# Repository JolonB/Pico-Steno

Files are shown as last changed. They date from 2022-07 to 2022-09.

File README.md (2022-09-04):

# Pico-Steno

An open-source Raspberry Pi Pico stenography keyboard.

I promise I'll write more here soon.

Gerber files can be found [here](hardware/gerber/).
I have not yet ordered a PCB with these gerber files, so they may have issues.

The bill of materials can be found [here](docs/bom/).

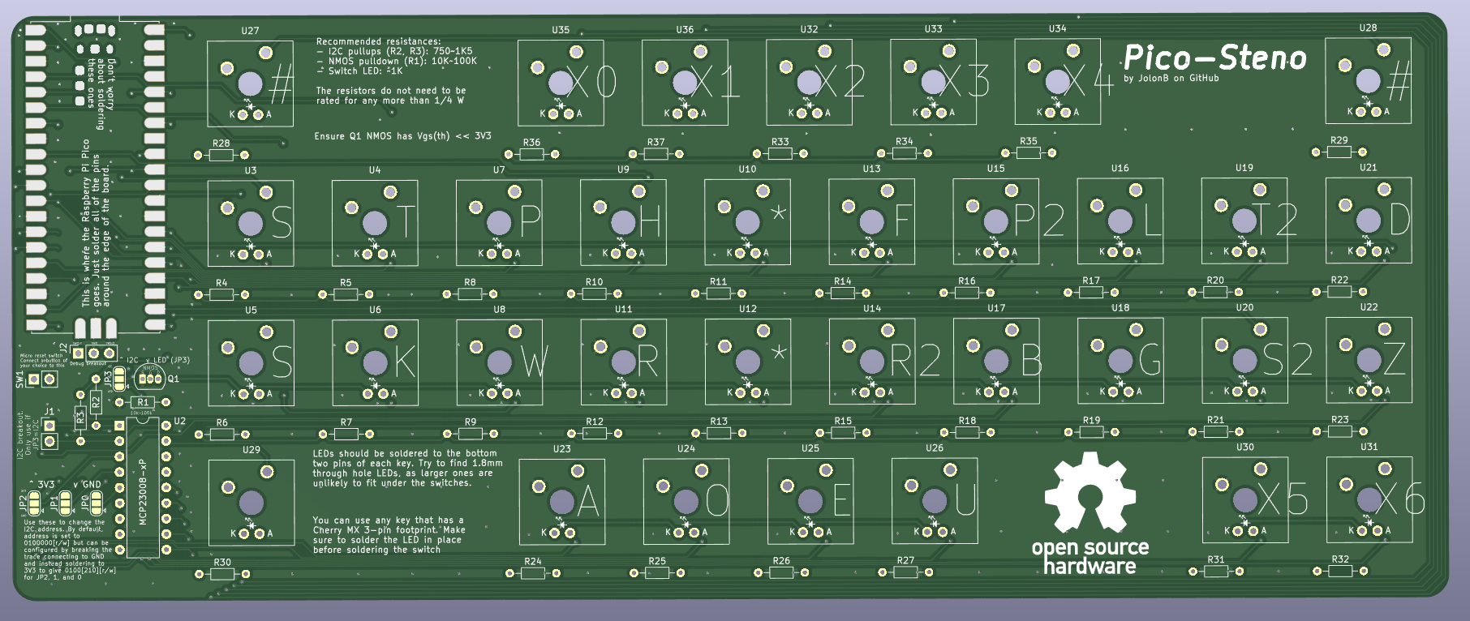
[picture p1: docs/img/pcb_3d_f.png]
pcb front


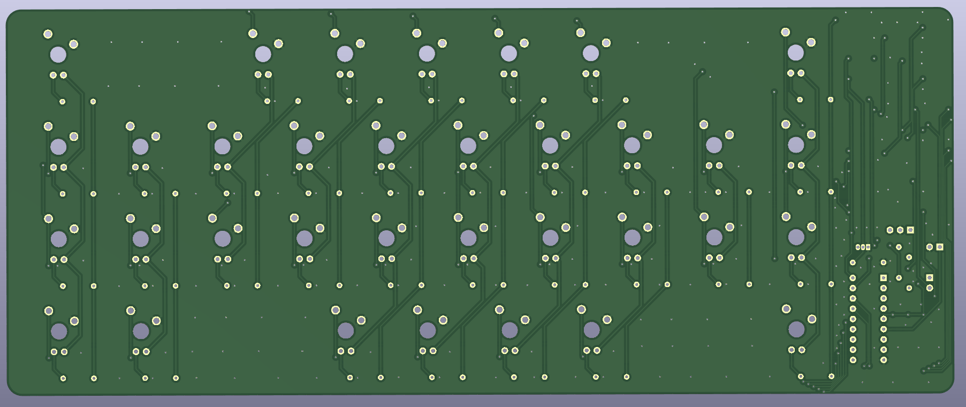
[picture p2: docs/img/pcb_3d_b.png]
pcb back


## Setup

### Flashing Pico

<!-- TODO add instructions for flashing the circuitpython firmware -->

To begin, you need to have `circup` installed so you can add libraries to your Pico.
Start by installing the dependencies:

```shell
sudo apt install -y git python3 python3-pip
```

And then install `circup`:

```shell
pip3 install --upgrade pip
pip3 install circup
```

You can update `circup` by running:

```shell
pip3 install --upgrade circup
```

Now, you can simply install the packages by plugging in your Pico which is running CircuitPython and running:

```shell
cd src/
circup install -r requirements.txt
```

### Compiling Code

To compile the code, you need `mpy-cross` installed on your PC.
You can download it from [here](https://adafruit-circuit-python.s3.amazonaws.com/index.html?prefix=bin/mpy-cross/) and download the latest version for your operating system (or look [here](https://learn.adafruit.com/welcome-to-circuitpython/frequently-asked-questions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) if the link is dead).

<!-- TODO add more notes here
Probably only need to compile the custom code, not the libraries. Might as well use circup (https://learn.adafruit.com/keep-your-circuitpython-libraries-on-devices-up-to-date-with-circup/prepare)
Later, could add an explanation for how to build a whole circuit python firmware with custom lib?? -->

### Loading .mpy files onto Pico

## Questions

### Why doesn't this use a keyboard matrix?

Good question.

1. The RPi Pico has enough GPIO pins to dedicate one to each key on a stenography keyboard.
Basically, I just though that was neat, so decided to do it that way.
I then decided I wanted optional extra keys, so added the IO extender.
1. This allows me to implement n-key rollover without needing any diodes; not that they are particularly expensive.

### Why is the circuit so messy?

That's what happens when each key is connected directly to the microcontroller without optimising the which switch connects to which pin.  
But hey, this is open source; if it bugs you, feel free to fork it!

## I can't detect my board

```shell
pip3 install adafruit-board-toolkit
python3 -c "import adafruit_board_toolkit.circuitpython_serial; print(adafruit_board_toolkit.circuitpython_serial.data_comports()[0].device)"
```

If you get `IndexError: tuple index out of range`, then no data port was detected.

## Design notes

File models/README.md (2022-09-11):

# Keycaps

The keycap has been generated by using the scripts made avilable by Robert Sheldon (rshelldiii on GitHub).
The keycap generator scripts for OpenSCAD can be found [here](https://github.com/rsheldiii/keyV2).

You can import `steno_key.stl` into the slicer of your choice.
I suggest reducing the top and bottom layer count to 3 and the wall line count to 2.
This is for two reasons: you don't need a super strong key and it allows more backlight through.
With just these changes, a full set of keys takes no more than 5 hours to print with a 0.16 mm layer height.

My `customizer.json` file used in the `customizer.scad` script is made available in this directory.
You should be able to import this and switch to the `flat` preset.
This may be useful if you want to make additional modifications to the keycap; adding labels, for example.

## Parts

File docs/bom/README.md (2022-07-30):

# Bill of Materials

The parts and prices shown in [`bom.csv`](bom.csv) are based on products available at DigiKey and, for most components, are only a suggestion.
The price isn't great, but you are able to purchase the same/similar components elsewhere for lower prices.
For example, AliExpress is a great place to look for the LEDs, MOSFETs, resistors, and even switches.  
As long as the component fits the footprint, there should be no issues.
Instead of buying proper Cherry MX switches, you could get pin-compatible switches from Kailh or Outemu for possibly half the price.  
If you want LED backlighting, make sure you choose an LED that fits in the switch.
The BOM uses a 1.8mm (green\*) LED which is the best type for Kailh switches.

\*Feel free to use any colour.

## Do I need to buy all of these?

No!

A "minimal" BOM is shown in [`bom_min.csv`](bom_min.csv).
This removes a few of the extra switches (marked by `Xn`) as well as the I2C expander than interfaces with them.

This *technically* isn't the true minimal BOM.
If you choose to, you can remove the LED backlighting by getting rid of:

- 1 switch (LED setting)
- 1 2N7000
- 27 LEDs
- 1 10k resistor
- 29 1k resistors

which will make the BOM consist of only the SC0915 (Raspberry Pi Pico) and the 26 remaining switches.
Buying the switches from AliExpress makes the true minimal *component* BOM no more than NZ$30 (excl. shipping).

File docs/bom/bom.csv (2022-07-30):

Index | Manufacturer Part Number | Manufacturer Name | Description | Requested Quantity 1 | Digi-Key Part Number 1 | Unit Price 1 | Extended Price 1 | Datasheet
1 | SC0915 | Raspberry Pi | RASPBERRY PI PICO RP2040 BOARD | 1 | 2648-SC0915CT-ND | 7.1 | 7.1 | https://datasheets.raspberrypi.com/pico/pico-datasheet.pdf
2 | MCP23008-E/P | Microchip Technology | IC I/O EXPANDER I2C 8B 18DIP | 1 | MCP23008-E/P-ND | 2.75 | 2.75 | https://ww1.microchip.com/downloads/en/DeviceDoc/MCP23008-MCP23S08-Data-Sheet-20001919F.pdf
3 | CF18JT10K0 | Stackpole Electronics Inc | RES 10K OHM 5% 1/8W AXIAL | 1 | CF18JT10K0CT-ND | 0.18 | 0.18 | https://www.seielect.com/catalog/sei-cf_cfm.pdf
4 | CF18JT1K00 | Stackpole Electronics Inc | RES 1K OHM 5% 1/8W AXIAL | 36 | CF18JT1K00CT-ND | 0.0584 | 2.1 | https://www.seielect.com/catalog/sei-cf_cfm.pdf
5 | 2N7000 | onsemi | MOSFET N-CH 60V 200MA TO92-3 | 1 | 2N7000FS-ND | 0.82 | 0.82 | https://rocelec.widen.net/view/pdf/orqxwkxkq1/ONSM-S-A0003544006-1.pdf?t.download=true&u=5oefqw
6 | MX1A-11NW | Cherry Americas LLC | SWITCH PUSH SPST-NO 0.01A 12V | 34 | CH160-ND | 1.4932 | 50.77 | https://media.digikey.com/pdf/Data%20Sheets/Cherry%20PDFs/MX%20Series.pdf
7 | WP4060GD | Kingbright | LED GREEN DIFFUSED T/H | 34 | 754-1373-ND | 0.496 | 16.86 | https://www.KingbrightUSA.com/images/catalog/SPEC/WP4060GD.pdf
 |  |  |  |  |  | Total | 80.58 | All prices in NZD

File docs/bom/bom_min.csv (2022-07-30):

Index | Manufacturer Part Number | Manufacturer Name | Description | Requested Quantity 1 | Digi-Key Part Number 1 | Unit Price 1 | Extended Price 1 | Datasheet
1 | SC0915 | Raspberry Pi | RASPBERRY PI PICO RP2040 BOARD | 1 | 2648-SC0915CT-ND | 7.1 | 7.1 | https://datasheets.raspberrypi.com/pico/pico-datasheet.pdf
2 | CF18JT10K0 | Stackpole Electronics Inc | RES 10K OHM 5% 1/8W AXIAL | 1 | CF18JT10K0CT-ND | 0.18 | 0.18 | https://www.seielect.com/catalog/sei-cf_cfm.pdf
3 | CF18JT1K00 | Stackpole Electronics Inc | RES 1K OHM 5% 1/8W AXIAL | 29 | CF18JT1K00CT-ND | 0.0584 | 1.69 | https://www.seielect.com/catalog/sei-cf_cfm.pdf
4 | 2N7000 | onsemi | MOSFET N-CH 60V 200MA TO92-3 | 1 | 2N7000FS-ND | 0.82 | 0.82 | https://rocelec.widen.net/view/pdf/orqxwkxkq1/ONSM-S-A0003544006-1.pdf?t.download=true&u=5oefqw
5 | MX1A-11NW | Cherry Americas LLC | SWITCH PUSH SPST-NO 0.01A 12V | 27 | CH160-ND | 1.4932 | 40.32 | https://media.digikey.com/pdf/Data%20Sheets/Cherry%20PDFs/MX%20Series.pdf
6 | WP4060GD | Kingbright | LED GREEN DIFFUSED T/H | 27 | 754-1373-ND | 0.496 | 13.39 | https://www.KingbrightUSA.com/images/catalog/SPEC/WP4060GD.pdf
 |  |  |  |  |  | Total | 63.5 | All prices in NZD

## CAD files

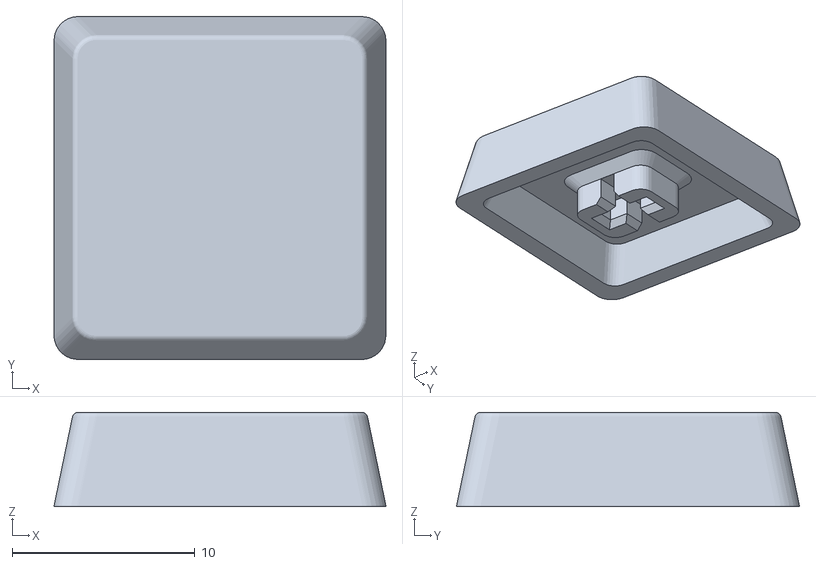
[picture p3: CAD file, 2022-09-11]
models/steno_key.stl
18.2 x 18.8 x 5.16

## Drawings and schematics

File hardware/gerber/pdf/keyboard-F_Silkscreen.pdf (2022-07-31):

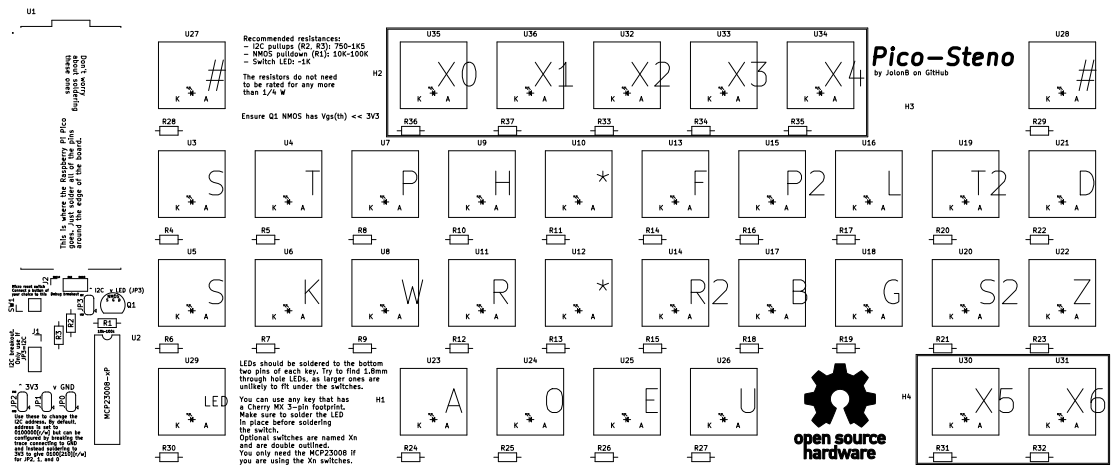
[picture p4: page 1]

The resistors do not need
to be rated for any more
than 1/4 W

by JolonB on GitHub

Debug breakout SWCLK This is where the Raspberry Pi Pico goes. Just solder all of the pins around the edge of the board.

GND Use these to change the
through hole LEDs, as larger ones are unlikely to fit under the switches. Micro reset switch Connect a button of your choice to this
U2 MCP23008-xP

and are double outlined. You only need the MCP23008 if you are using the Xn switches. D

two pins of each key. Try to find 1.8mm

a Cherry MX 3-pin footprint. Make sure to solder the LED

I2C address. By default, address is set to
0100000[r/w] but can be
configured by breaking the
trace connecting to GND
and instead soldering to
3V3 to give 0100[210][r/w]

in place before soldering
the switch. Optional switches are named Xn

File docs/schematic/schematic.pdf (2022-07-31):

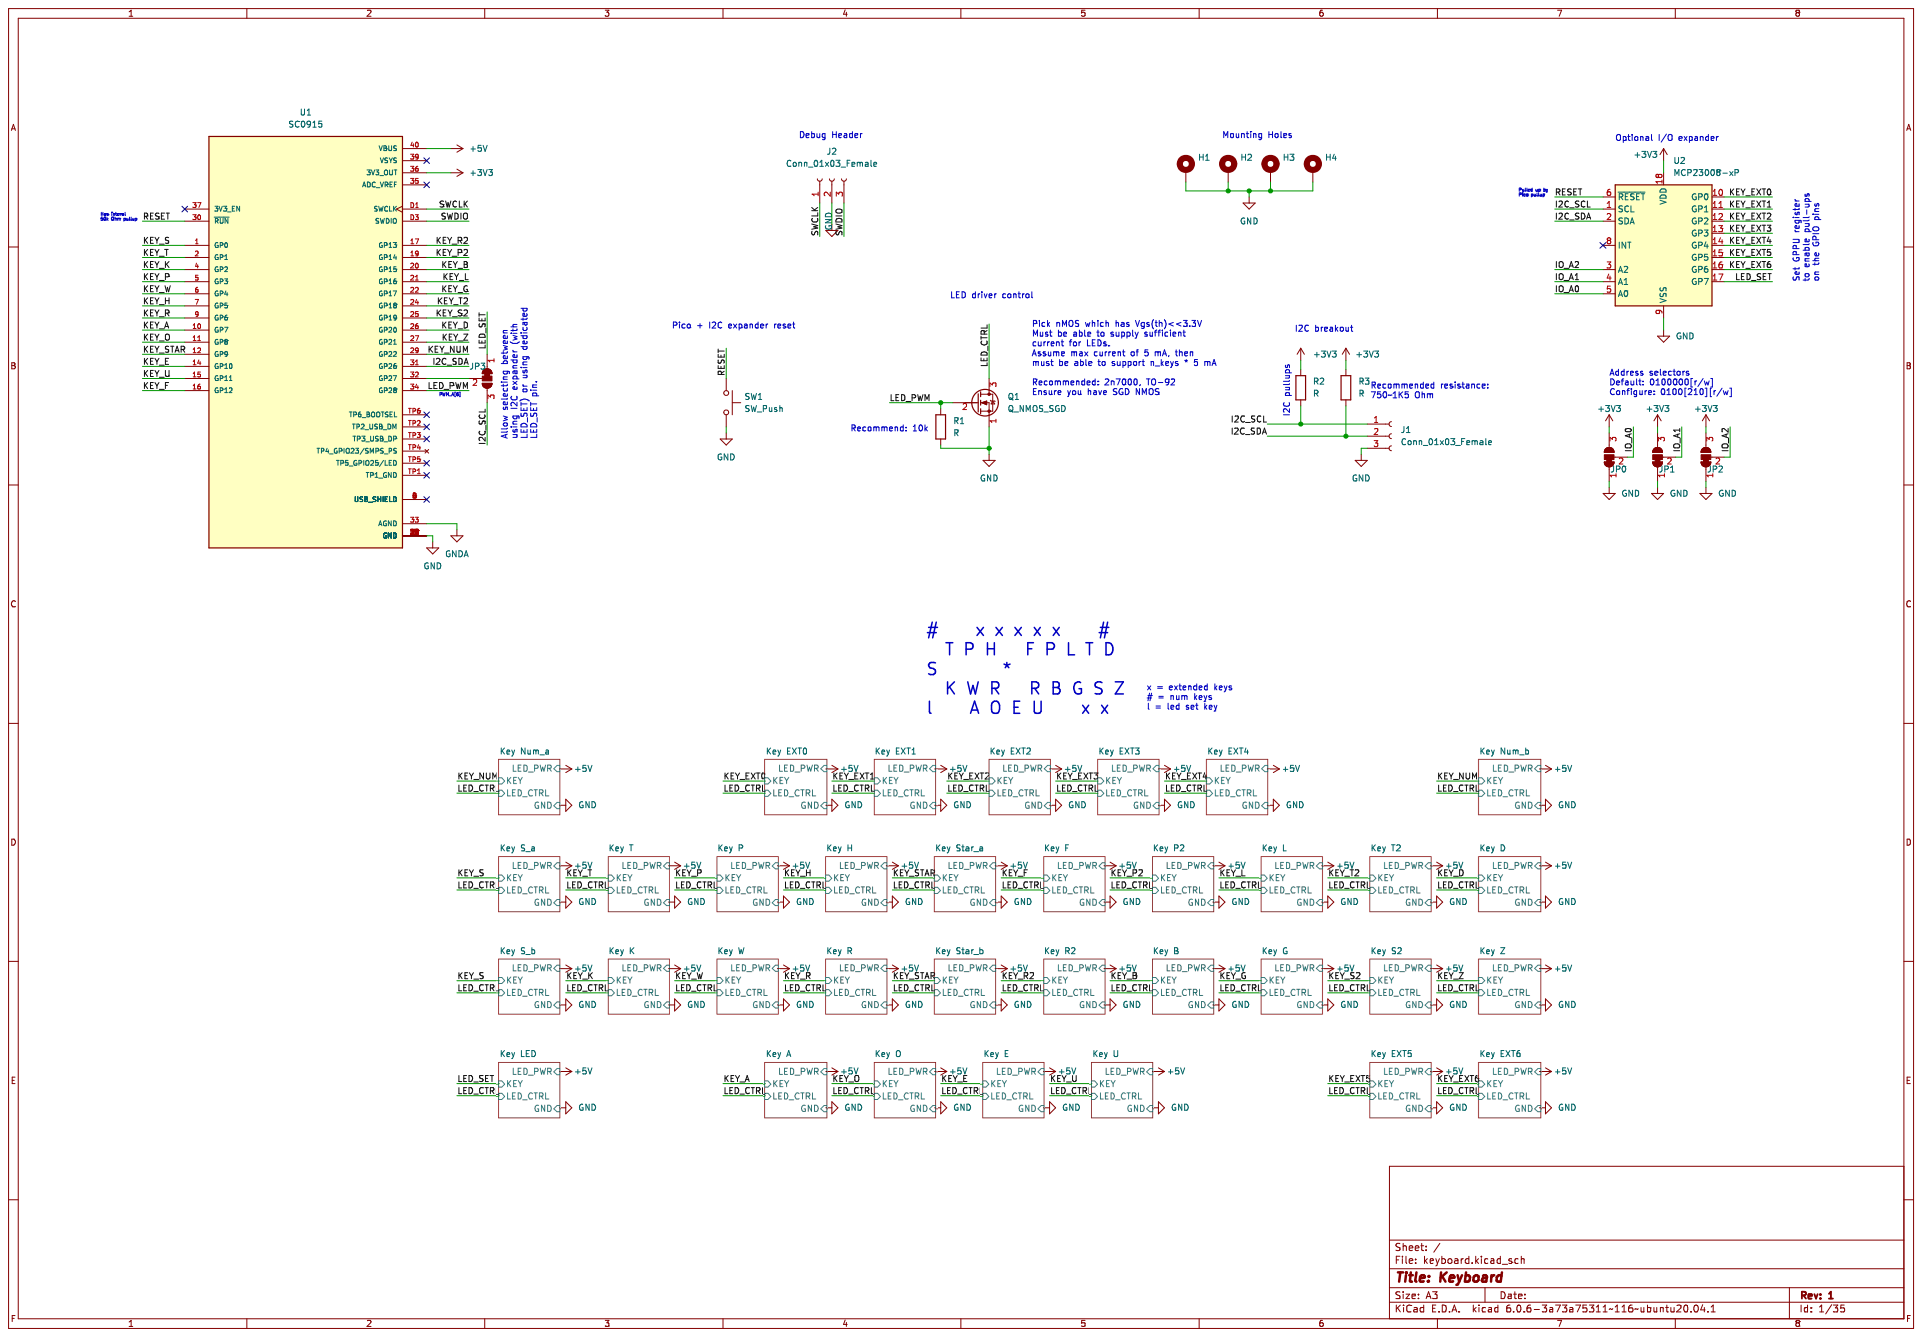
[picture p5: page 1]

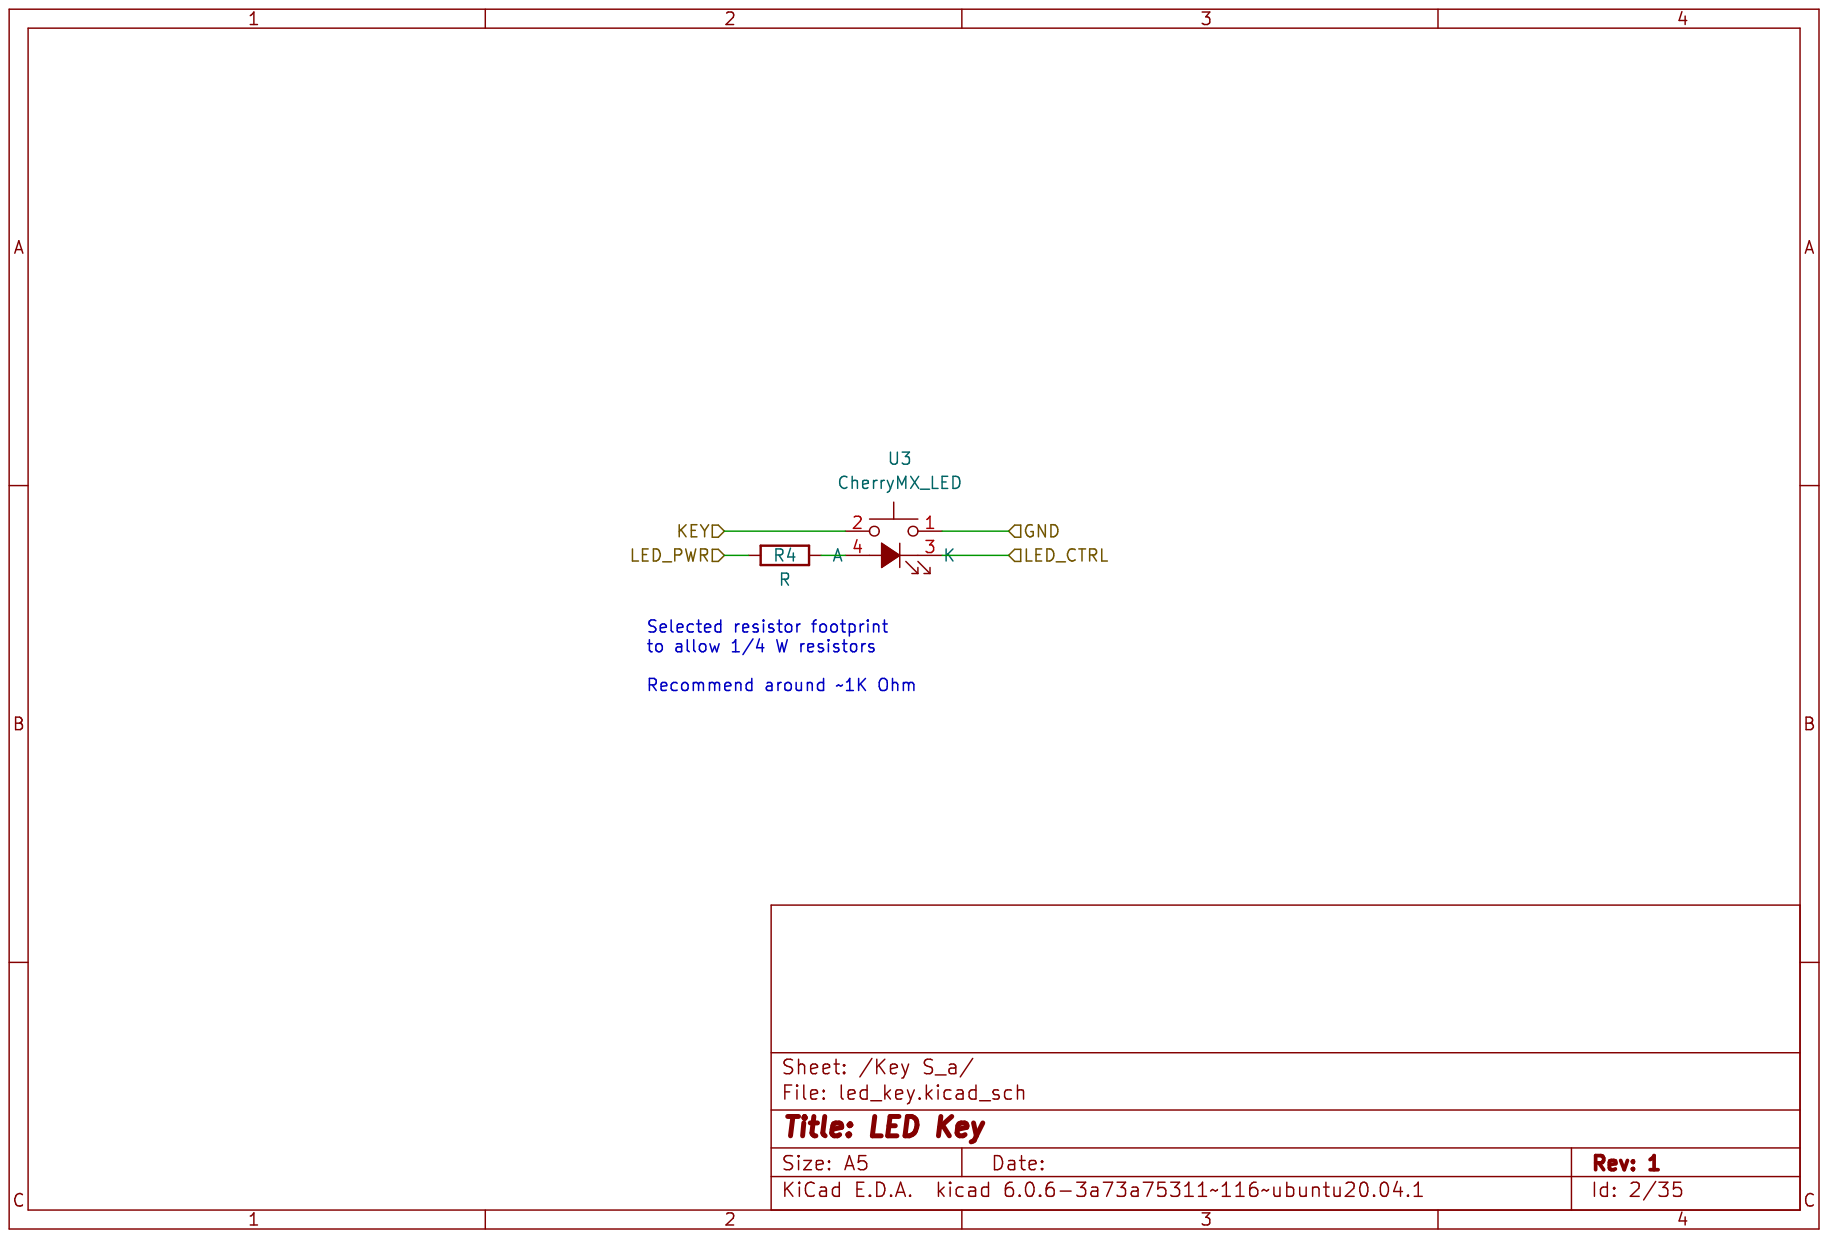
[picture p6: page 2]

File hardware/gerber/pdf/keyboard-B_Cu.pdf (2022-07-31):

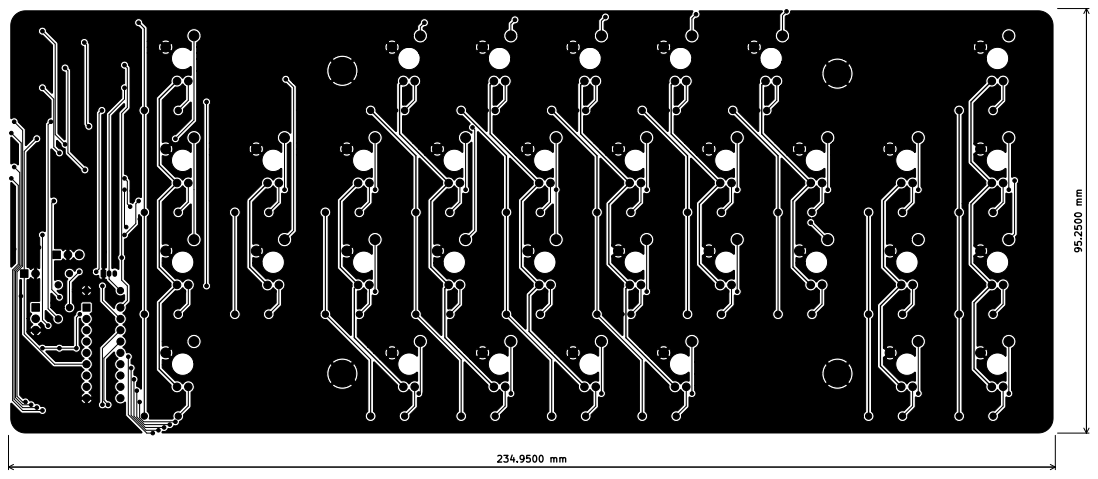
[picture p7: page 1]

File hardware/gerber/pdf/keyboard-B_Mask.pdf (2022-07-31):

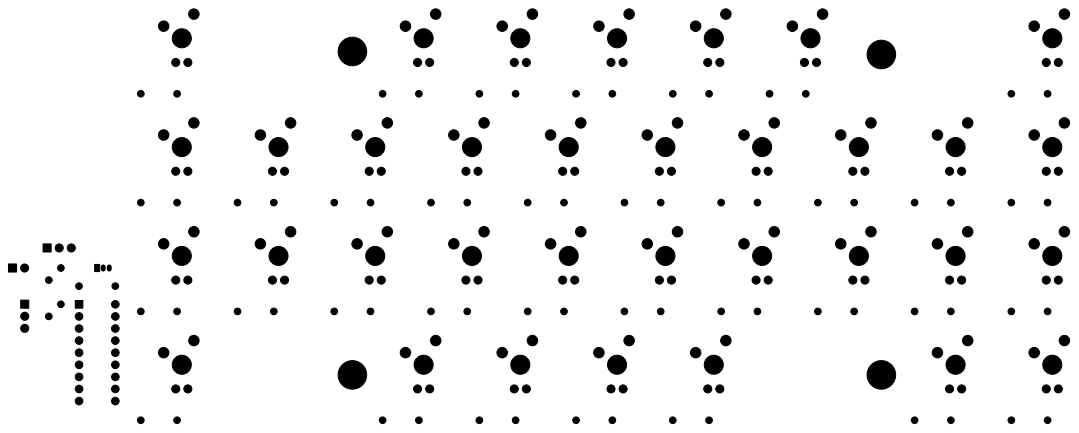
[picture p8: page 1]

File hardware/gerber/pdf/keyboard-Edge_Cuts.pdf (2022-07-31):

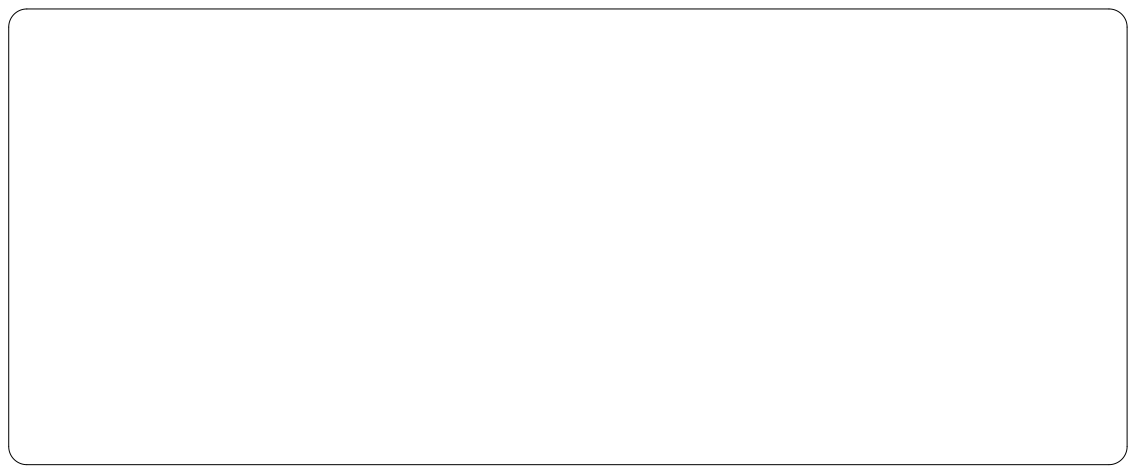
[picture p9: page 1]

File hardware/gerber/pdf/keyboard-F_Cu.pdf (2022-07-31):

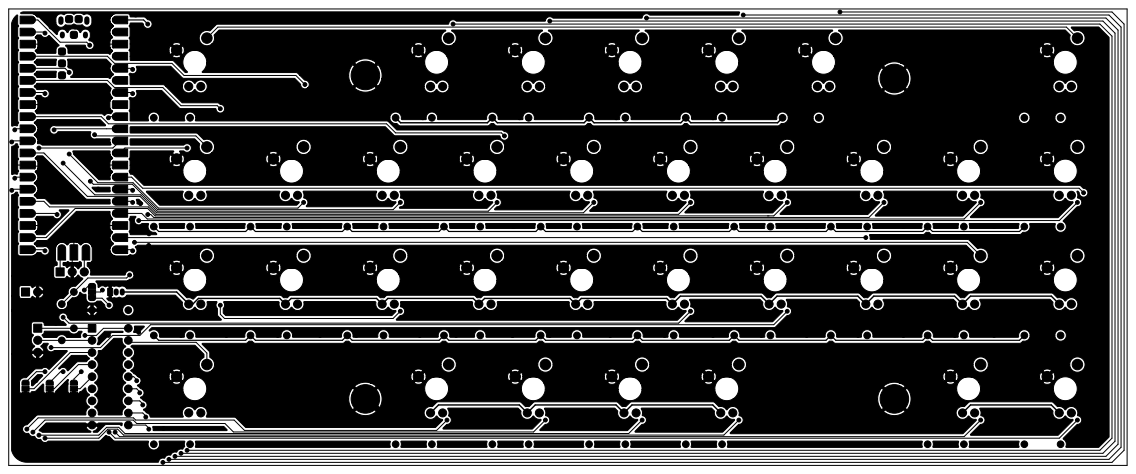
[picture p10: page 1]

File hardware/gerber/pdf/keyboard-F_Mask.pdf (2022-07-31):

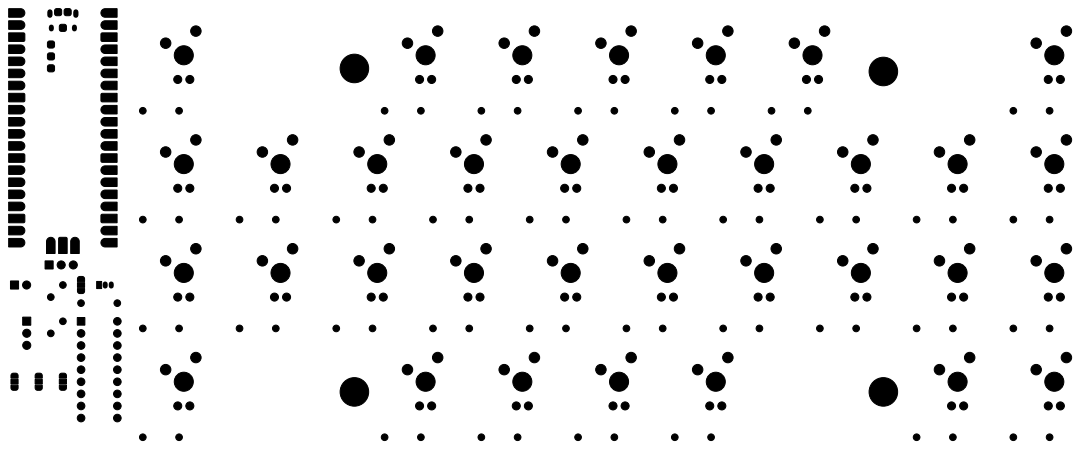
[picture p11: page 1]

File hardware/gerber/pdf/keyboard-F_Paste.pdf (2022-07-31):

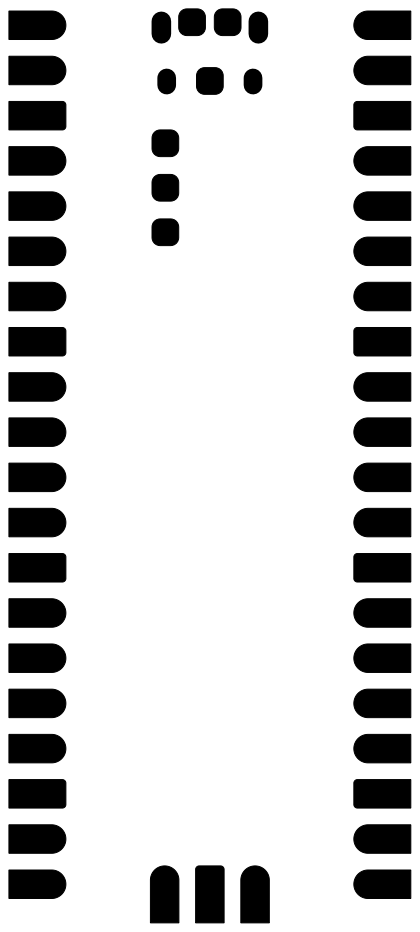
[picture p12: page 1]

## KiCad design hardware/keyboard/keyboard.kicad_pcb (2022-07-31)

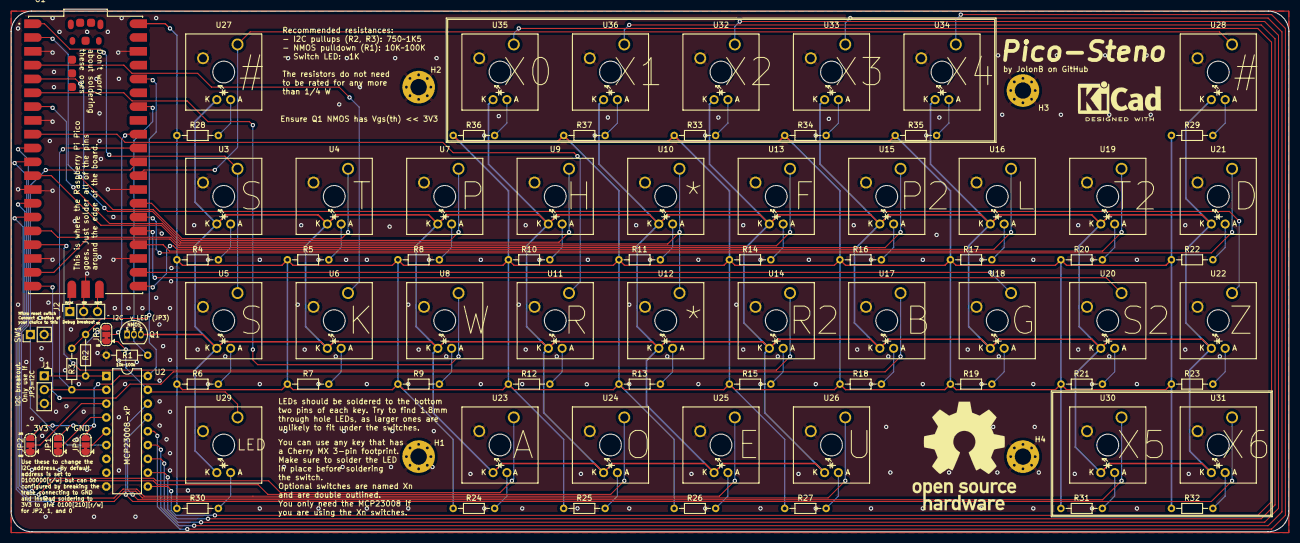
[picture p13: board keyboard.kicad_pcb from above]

Board: 2 copper layers, 234.9 x 95.7 mm, 85 parts (0 on the bottom side), 79 nets.

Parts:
H1, H2, H3, H4: MountingHole_Pad; MountingHole_3mm_Pad_Via
J1, J2: Conn_01x03_Female; PinSocket_1x03_P2.54mm_Vertical
JP0, JP1, JP2, JP3: SolderJumper_3_Bridged12; SolderJumper-3_P1.3mm_Bridged12_RoundedPad1.0x1.5mm
Q1: Q_NMOS_SGD; TO-92L_Inline
R1, R2, R3, R4, R5, R6, R7, R8, R9, R10, R11, R12, R13, R14, R15, R16, R17, R18, R19, R20, R21, R22, R23, R24, R25, R26, R27, R28, R29, R30, R31, R32, R33, R34, R35, R36, R37: R; R_Axial_DIN0204_L3.6mm_D1.6mm_P7.62mm_Horizontal
SW1: SW_Push; PinHeader_1x02_P2.54mm_Vertical
U1: SC0915; MODULE_SC0915
U2: MCP23008-xP; DIP-18_W7.62mm
U3, U4, U5, U6, U7, U8, U9, U10, U11, U12, U13, U14, U15, U16, U17, U18, U19, U20, U21, U22, U23, U24, U25, U26, U27, U28, U29, U30, U31, U32, U33, U34, U35, U36: CherryMX_LED; CherryMX_1.00u_LED

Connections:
+3V3: JP0.3 (B), JP1.3 (B), JP2.3 (B), R2.1, R3.1, U1.36 (3V3_OUT), U2.18 (VDD)
+5V: R4.1, R5.1, R6.1, R7.1, R8.1, R9.1, R10.1, R11.1, R12.1, R13.1, R14.1, R15.1, R16.1, R17.1, R18.1, R19.1, R20.1, R21.1, R22.1, R23.1, R24.1, R25.1, R26.1, R27.1, R28.1, R29.1, R30.1, R31.1, R32.1, R33.1, R34.1, R35.1, R36.1, R37.1, U1.40 (VBUS)
/I2C_SCL: J1.1, JP3.3 (B), R2.2, U2.1 (SCL)
/I2C_SDA: J1.2, R3.2, U1.31 (GP26), U2.2 (SDA)
/IO_A0: JP0.2 (C), U2.5 (A0)
/IO_A1: JP1.2 (C), U2.4 (A1)
/IO_A2: JP2.2 (C), U2.3 (A2)
/KEY_A: U1.10 (GP7), U23.2
/KEY_B: U1.20 (GP15), U17.2
/KEY_D: U1.26 (GP20), U21.2
/KEY_E: U1.14 (GP10), U25.2
/KEY_EXT0: U2.10 (GP0), U35.2
/KEY_EXT1: U2.11 (GP1), U36.2
/KEY_EXT2: U2.12 (GP2), U32.2
/KEY_EXT3: U2.13 (GP3), U33.2
/KEY_EXT4: U2.14 (GP4), U34.2
/KEY_EXT5: U2.15 (GP5), U30.2
/KEY_EXT6: U2.16 (GP6), U31.2
/KEY_F: U1.16 (GP12), U13.2
/KEY_G: U1.22 (GP17), U18.2
/KEY_H: U1.7 (GP5), U9.2
/KEY_K: U1.4 (GP2), U6.2
/KEY_L: U1.21 (GP16), U16.2
/KEY_NUM: U1.29 (GP22), U27.2, U28.2
/KEY_O: U1.11 (GP8), U24.2
/KEY_P: U1.5 (GP3), U7.2
/KEY_P2: U1.19 (GP14), U15.2
/KEY_R: U1.9 (GP6), U11.2
/KEY_R2: U1.17 (GP13), U14.2
/KEY_S: U1.1 (GP0), U3.2, U5.2
/KEY_S2: U1.25 (GP19), U20.2
/KEY_STAR: U1.12 (GP9), U10.2, U12.2
/KEY_T: U1.2 (GP1), U4.2
/KEY_T2: U1.24 (GP18), U19.2
/KEY_U: U1.15 (GP11), U26.2
/KEY_W: U1.6 (GP4), U8.2
/KEY_Z: U1.27 (GP21), U22.2
/LED_CTRL: Q1.3 (D), U3.3 (K), U4.3 (K), U5.3 (K), U6.3 (K), U7.3 (K), U8.3 (K), U9.3 (K), U10.3 (K), U11.3 (K), U12.3 (K), U13.3 (K), U14.3 (K), U15.3 (K), U16.3 (K), U17.3 (K), U18.3 (K), U19.3 (K), U20.3 (K), U21.3 (K), U22.3 (K), U23.3 (K), U24.3 (K), U25.3 (K), U26.3 (K), U27.3 (K), U28.3 (K), U29.3 (K), U30.3 (K), U31.3 (K), U32.3 (K), U33.3 (K), U34.3 (K), U35.3 (K), U36.3 (K)
/LED_PWM: Q1.2 (G), R1.1, U1.34 (GP28)
/LED_SET: JP3.1 (A), U2.17 (GP7), U29.2
/RESET: SW1.1, U1.30 (~RUN), U2.6 (~RESET)
/SWCLK: J2.1, U1.D1 (SWCLK)
/SWDIO: J2.3, U1.D3 (SWDIO)
GND: H1.1, H2.1, H3.1, H4.1, J1.3, J2.2, JP0.1 (A), JP1.1 (A), JP2.1 (A), Q1.1 (S), R1.2, SW1.2, U1.3 (GND), U1.8 (GND), U1.13 (GND), U1.18 (GND), U1.23 (GND), U1.28 (GND), U1.38 (GND), U1.D2 (GND), U2.9 (VSS), U3.1, U4.1, U5.1, U6.1, U7.1, U8.1, U9.1, U10.1, U11.1, U12.1, U13.1, U14.1, U15.1, U16.1, U17.1, U18.1, U19.1, U20.1, U21.1, U22.1, U23.1, U24.1, U25.1, U26.1, U27.1, U28.1, U29.1, U30.1, U31.1, U32.1, U33.1, U34.1, U35.1, U36.1
unnamed: JP3.2 (C), U1.32 (GP27)
unnamed: R4.2, U3.4 (A)
unnamed: R5.2, U4.4 (A)
unnamed: R6.2, U5.4 (A)
unnamed: R7.2, U6.4 (A)
unnamed: R8.2, U7.4 (A)
unnamed: R9.2, U8.4 (A)
unnamed: R10.2, U9.4 (A)
unnamed: R11.2, U10.4 (A)
unnamed: R12.2, U11.4 (A)
unnamed: R13.2, U12.4 (A)
unnamed: R14.2, U13.4 (A)
unnamed: R15.2, U14.4 (A)
unnamed: R16.2, U15.4 (A)
unnamed: R17.2, U16.4 (A)
unnamed: R18.2, U17.4 (A)
unnamed: R19.2, U18.4 (A)
unnamed: R20.2, U19.4 (A)
unnamed: R21.2, U20.4 (A)
unnamed: R22.2, U21.4 (A)
unnamed: R23.2, U22.4 (A)
unnamed: R24.2, U23.4 (A)
unnamed: R25.2, U24.4 (A)
unnamed: R26.2, U25.4 (A)
unnamed: R27.2, U26.4 (A)
unnamed: R28.2, U27.4 (A)
unnamed: R29.2, U28.4 (A)
unnamed: R30.2, U29.4 (A)
unnamed: R31.2, U30.4 (A)
unnamed: R32.2, U31.4 (A)
unnamed: R33.2, U32.4 (A)
unnamed: R34.2, U33.4 (A)
unnamed: R35.2, U34.4 (A)
unnamed: R36.2, U35.4 (A)
unnamed: R37.2, U36.4 (A)

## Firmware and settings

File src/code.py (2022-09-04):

"""
THIS IS SAMPLE CODE
DON'T BOTHER RUNNING THIS
"""

import asyncio

import board

import backlight
import button
import keymap
import txbolt


PROCESS_TIMEOUT = 0.001


async def process_keys(keys, tx: txbolt.TXBolt):
    # Track the timestamp of each key press
    key_timestamps = [0.0] * len(keys)
    for key in keys:
        asyncio.create_task(key.start())

    print("Buttons started")

    keys_pressed = set()
    while True:
        none_pressed = True
        for index, key in enumerate(keys):
            if key.pressed:
                key_action = key.key

                if callable(key_action):
                    pressed_time = key.press_stamp
                    # If the key is callable, call the function only if this is a new keypress
                    if pressed_time != key_timestamps[index]:
                        # Also update the timestamp
                        key_timestamps[index] = pressed_time
                        key_action()
                else:
                    # Otherwise, assume it is a steno key and send the data
                    none_pressed = False
                    keys_pressed.add(key_action)

        # If keys have been pressed, but none are pressed anymore, send them
        if none_pressed and keys_pressed:
            tx.write_packet(keys_pressed)
            keys_pressed = set()

        await asyncio.sleep(PROCESS_TIMEOUT)


async def main():
    # Create a backlight, which will be mapped to the pin with the LED keymap
    bklight = backlight.Backlight(board.GP28)

    # Set up buttons
    buttons = []
    for pin, keycode in keymap.steno_keys.items():
        buttons.append(button.Button(pin, keycode))
    for pin, keycode in keymap.extra_keys.items():
        if keycode == ("LED",):
            key = button.Button(pin, bklight.increment_mode)
        buttons.append(key)

    tx = txbolt.TXBolt()

    await asyncio.gather(bklight.start(), process_keys(buttons, tx))


if __name__ == "__main__":
    asyncio.run(main())

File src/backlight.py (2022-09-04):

import asyncio
import math

import pwmio
import adafruit_simplemath as smath
import adafruit_logging as logging


class Backlight:
    __MAX_DUTY = 65535 // 2

    def __init__(self, pin, fade_rate:float=1.0):
        # Initialise PWM pin for backlight control
        self.__pin_name = str(pin)
        self.__logger = logging.getLogger("Backlight")

        # Set initial mode to OFF
        self.__mode_functions = [
            self.off,
            self.on_25,
            self.on_50,
            self.on_75,
            self.on_100,
            self.blink,
            self.fade,
        ]
        self.__mode = 0
        self.__fade_rate = fade_rate

        self.__init_led(pin)

    def __get_duty_cycle(self, duty_0_1) -> int:
        """Convert the duty cycle from 0-1 to 0-2^16

        Args:
            duty_0_1 (float): A duty cycle between 0 and 1
        """
        return int(smath.map_range(duty_0_1, 0, 1, 0, self.__MAX_DUTY))

    def __sin_func(self, duty_0_1:float) -> float:
        return (1 - math.cos(duty_0_1*math.pi)) / 2

    def __log(self, level, msg):
        self.__logger.log(level, "({}) {}".format(self.__pin_name, msg))

    def __init_led(self, pin):
        self.__led = pwmio.PWMOut(pin, duty_cycle=0, frequency=5000)
        self.set_duty_cycle(0)

        self.__log(logging.INFO, "Backlight control configured on pin {}".format(pin))
        self.__pin_name = str(pin)

    def set_duty_cycle(self, duty_0_1):
        self.__led.duty_cycle = self.__get_duty_cycle(duty_0_1)

    def increment_mode(self):
        self.__mode += 1
        # Cycle back to the start if we've hit the end
        if self.__mode >= len(self.__mode_functions):
            self.__mode = 0

    async def start(self, pin=None, fade_rate=None):
        # Override previous values if new ones are provided
        if pin is not None:
            self.__led.deinit()
            self.__init_led(pin)
        if fade_rate is not None:
            self.__fade_rate = fade_rate

        # Start the backlight loop
        while True:
            self.__log(logging.DEBUG, "Backlight set to mode {}".format(self.__mode))
            await self.__mode_functions[self.__mode]()

    async def off(self):
        self.set_duty_cycle(0)
        while self.__mode == 0:
            await asyncio.sleep(0.5)

    async def on_25(self):
        self.set_duty_cycle(0.25)
        while self.__mode == 1:
            await asyncio.sleep(0.5)

    async def on_50(self):
        self.set_duty_cycle(0.5)
        while self.__mode == 2:
            await asyncio.sleep(0.5)

    async def on_75(self):
        self.set_duty_cycle(0.75)
        while self.__mode == 3:
            await asyncio.sleep(0.5)

    async def on_100(self):
        self.set_duty_cycle(1)
        while self.__mode == 4:
            await asyncio.sleep(0.5)

    async def blink(self):
        while self.__mode == 5:
            self.set_duty_cycle(0)
            await asyncio.sleep(0.5)
            self.set_duty_cycle(0.5)
            await asyncio.sleep(0.5)

    async def fade(self):
        sleep_time = 0.01
        fade_amount = sleep_time / self.__fade_rate
        brightness = 0.0

        while self.__mode == 6:
            self.set_duty_cycle(self.__sin_func(brightness))
            brightness += fade_amount
            # Reverse the fading direction if we've hit the end of the fade
            if not (0 <= brightness <= 1):
                fade_amount = -fade_amount
            await asyncio.sleep(sleep_time)

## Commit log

2022-07-26 Add initial keyboard design
    [keyboard.kicad_pcb, keyboard.kicad_sch, led_key.kicad_sch]
2022-07-30 Add documentation to PCB
    [keyboard.kicad_pcb]
2022-07-30 Add BOM and images
    [bom.csv, bom_min.csv]
2022-07-30 Create gerber files
    [keyboard-B_Cu.gbl, keyboard-B_Cu.gbr, keyboard-B_Mask.gbr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]
2022-07-30 Add gerber PDFs
2022-07-31 Update I2C header
    [keyboard.kicad_pcb, keyboard.kicad_sch]
2022-07-31 Add mounting holes
    [keyboard-B_Cu.gbl, keyboard-B_Mask.gbs, keyboard-B_Paste.gbp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]
2022-07-31 Add KiCad logo to PCB
    [keyboard-B_Cu.gbl, keyboard-B_Mask.gbs, keyboard-B_Paste.gbp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]
2022-08-05 Add button library using asyncio
2022-08-06 Add backlight class
    Also improve the button class
2022-09-11 Add keycap model
    [steno_key.stl]
